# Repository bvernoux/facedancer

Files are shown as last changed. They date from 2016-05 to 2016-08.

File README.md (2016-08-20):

FaceDancer21+

Based on Facedancer21 (By Travis Goodspeed) but smaller (65.9mm x21 mm) with improved routing, decoupling capacitor/USB traces.

For more details see original (Travis Goodspeed) FaceDancer21 website:
http://goodfet.sourceforge.net/hardware/facedancer21

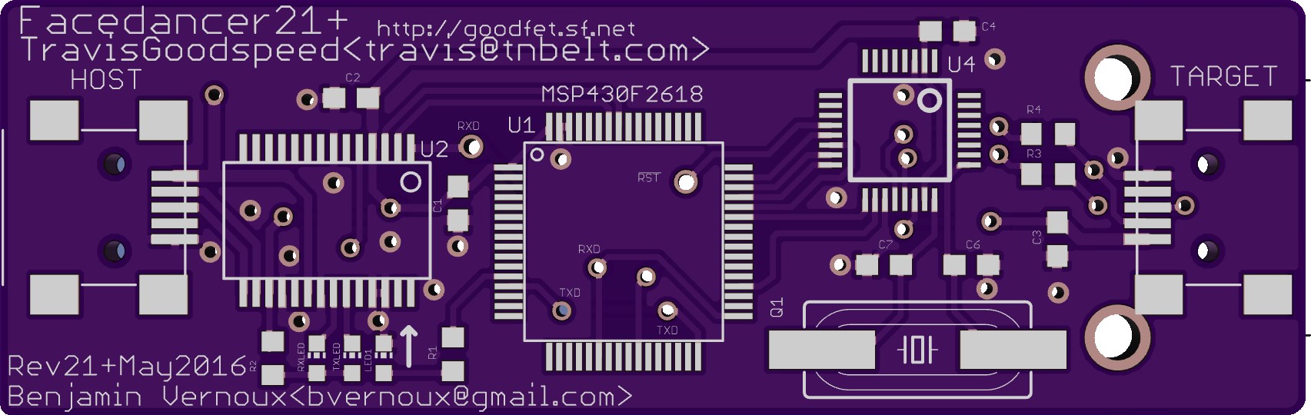
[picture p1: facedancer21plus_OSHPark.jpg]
FaceDancer21+ PCB OSHPark


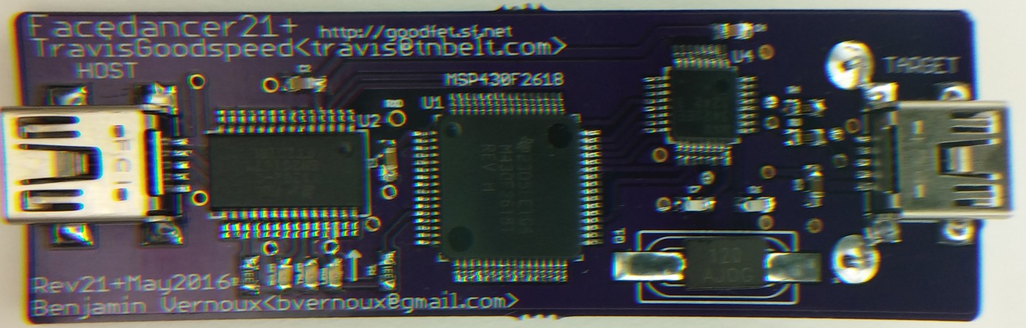
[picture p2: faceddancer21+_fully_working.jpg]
FaceDancer21+ Built Fully Working


See also PCB on OSH Park
https://oshpark.com/shared_projects/DaynyAWY

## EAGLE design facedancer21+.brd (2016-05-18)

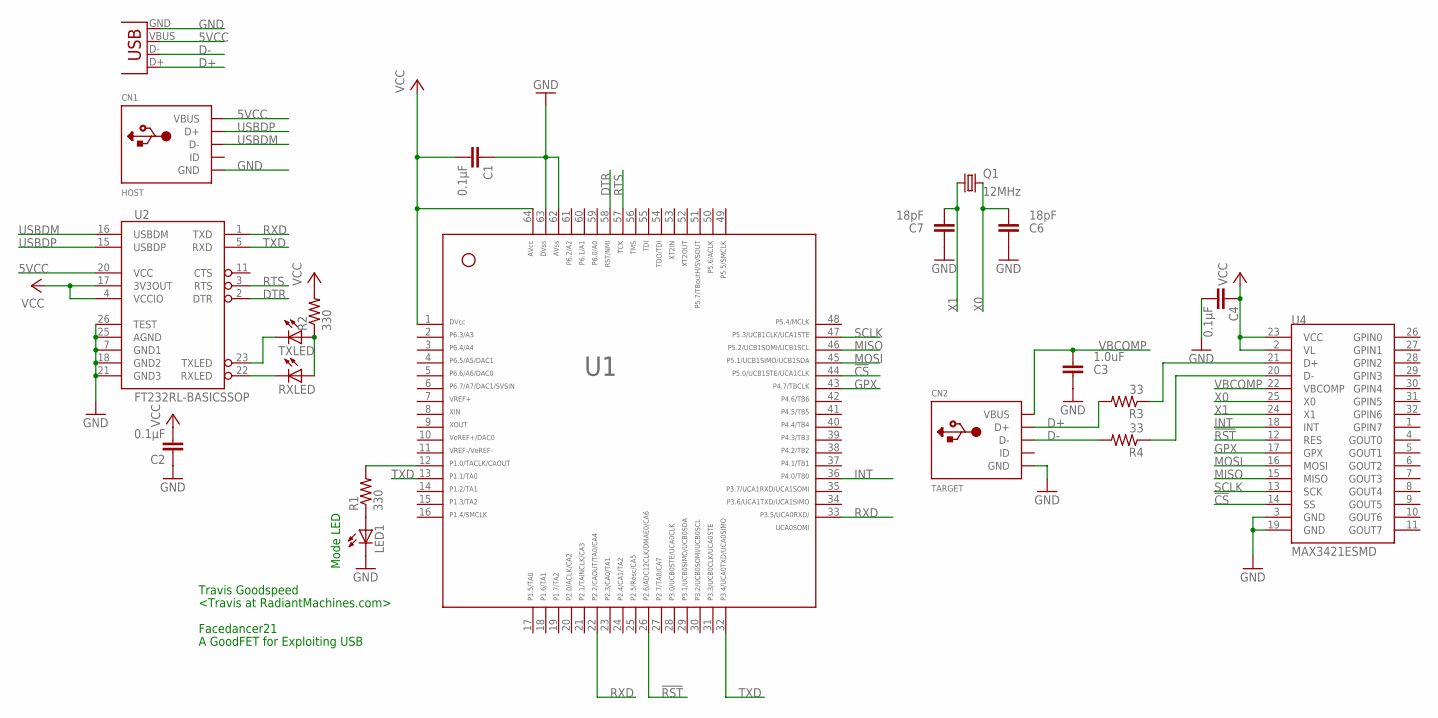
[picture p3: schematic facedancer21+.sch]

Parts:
C1, C2, C4: 0.1µF; C0603
C3: 1.0uF; C0603
C6, C7: 18pF; C0603
CN1: HOST; USB-MINIB
CN2: TARGET; USB-MINIB
CN3: USB-A-S
LED1: LEDCHIP-LED0603; CHIP-LED0603
Q1: 12MHz; HC49UP
R1, R2: 330; R0603
R3, R4: 33; R0603
RXLED: LEDCHIP-LED0603; CHIP-LED0603
TXLED: LEDCHIP-LED0603; CHIP-LED0603
U1: F261X---PM64; PM/PAG64
U2: FT232RL-BASICSSOP; SSOP28DB
U4: MAX3421ESMD; TQFP32-5MM

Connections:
5VCC: CN1.VBUS, CN3.VBUS, U2.20 (VCC)
!CS: U1.44, U4.14 (SS)
!RST: U1.26, U4.12 (RES)
D+: CN2.D+, CN3.D+, R3.2
D-: CN2.D-, CN3.D-, R4.2
DMINUS: R4.1, U4.20 (D-)
DPLUS: R3.1, U4.21 (D+)
DTR: U1.58, U2.2 (DTR)
GND: C1.1, C2.1, C3.1, C4.2, C6.1, C7.1, CN1.GND, CN2.GND, CN3.GND, LED1.C, U1.62, U1.63, U2.7 (GND1), U2.18 (GND2), U2.21 (GND3), U2.25 (AGND), U2.26 (TEST), U4.3 (GND), U4.19 (GND)
GPX: U1.43, U4.17 (GPX)
INT: U1.36, U4.18 (INT)
MISO: U1.46, U4.15 (MISO)
MOSI: U1.45, U4.16 (MOSI)
unnamed: R1.2, U1.12
unnamed: LED1.A, R1.1
unnamed: RXLED.C, U2.22 (RXLED)
unnamed: TXLED.C, U2.23 (TXLED)
unnamed: R2.1, RXLED.A, TXLED.A
RTS: U1.57, U2.3 (RTS)
RXD: U1.22, U1.33, U2.1 (TXD)
SCLK: U1.47, U4.13 (SCK)
TXD: U1.13, U1.32, U2.5 (RXD)
USBDM: CN1.D-, U2.16 (USBDM)
USBDP: CN1.D+, U2.15 (USBDP)
VBCOMP: C3.2, CN2.VBUS, U4.22 (VBCOMP)
VCC: C1.2, C2.2, C4.1, R2.2, U1.1, U1.64, U2.4 (VCCIO), U2.17 (3V3OUT), U4.2 (VL), U4.23 (VCC)
X0: C6.2, Q1.2, U4.25 (X0)
X1: C7.2, Q1.1, U4.24 (X1)

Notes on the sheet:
Mode LED
Travis Goodspeed
<Travis at RadiantMachines.com>
Facedancer21
A GoodFET for Exploiting USB

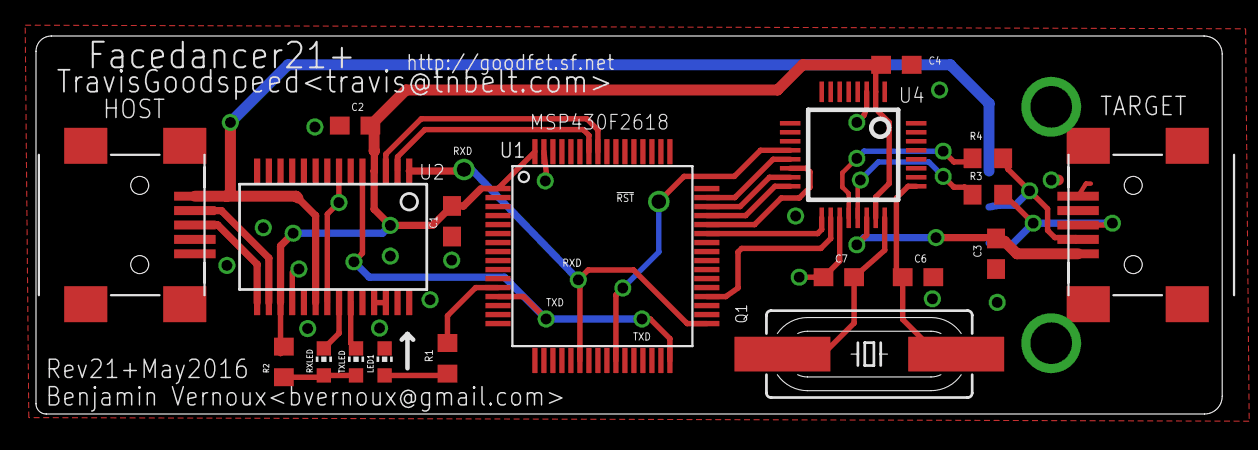
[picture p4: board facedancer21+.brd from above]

Board: 2 copper layers, 65.9 x 21.0 mm, 20 parts (1 on the bottom side), 28 nets.

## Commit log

2016-05-18 Add facedancer21+ Eagle 7.1.0 Board + Schematic
    [facedancer21+.brd, facedancer21+.sch]
2016-05-18 Add facedancer21+_top.png image and Gerber files
    [facedancer21+.GBL, facedancer21+.GBO, facedancer21+.GBP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]

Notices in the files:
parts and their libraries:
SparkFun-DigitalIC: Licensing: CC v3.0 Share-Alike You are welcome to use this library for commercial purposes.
